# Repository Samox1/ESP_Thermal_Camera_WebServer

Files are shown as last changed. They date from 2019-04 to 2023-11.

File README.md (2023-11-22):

# ESP_Thermal_Camera_WebServer

Welcome to see the micro project based on ESP32. <br>
Thermal Camera based on: <br>
1) ESP32 (Wrover)
2) MLX 90640 Thermal Camera 32x24 pixels
3) 0.95' OLED (SD1331)
4) ESPAsyncWebServer
5) SPIFFS - file system 
<br>

Important features - TO DO LIST:
- [x] Grabbing thermal image from MLX90640
- [x] Test image on OLED
- [x] Show thermal image on OLED
- [x] Build WebServer with ESPAsyncWebServer
- [x] Automatic update of variables (e.g. MaxTemp) on Website
- [x] Save thermal image as picture (BMP) in SPIFFS
- [x] Show Thermal Image (BMP) on Website
- [x] Automatic update of BMP (suitable SetInterval in <script>)
- [x] Case - 3D Model and print it on FDM 3D Printer
- [ ] Tweak updating Thermal Image (now SetInterval set to 1 sec - buggy image if set <1sec or there is more Clients)
- [ ] Reducing overall latency (Issue #2)
- [ ] Maybe Stream thermal image to Website (because why not) - faster updating
- [ ] Add Switch on Website to On/Off OLED display

Note: 10/10/2019<br>
I have MLX90640 files that are 6 months old. The latest files from Melexis contain a bug in the MLX90640_API.cpp file.

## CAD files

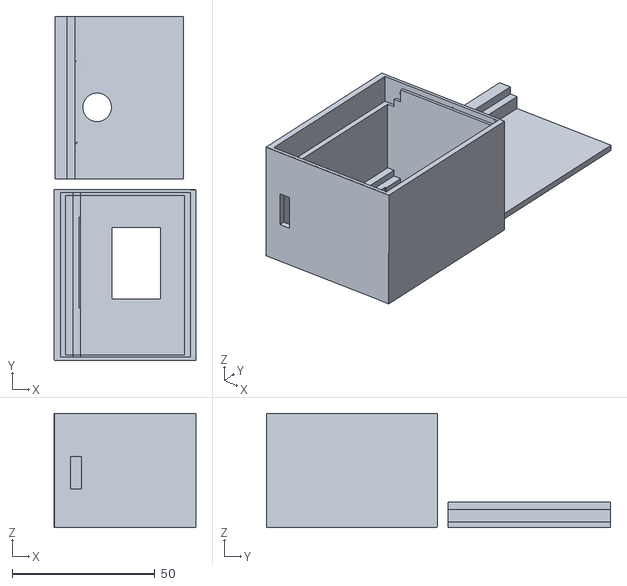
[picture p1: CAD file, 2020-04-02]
3D Model/Thermal_Camera_ESP32_MLX90640_ver_1-2_STL.stl
49.7 x 120.5 x 40.1

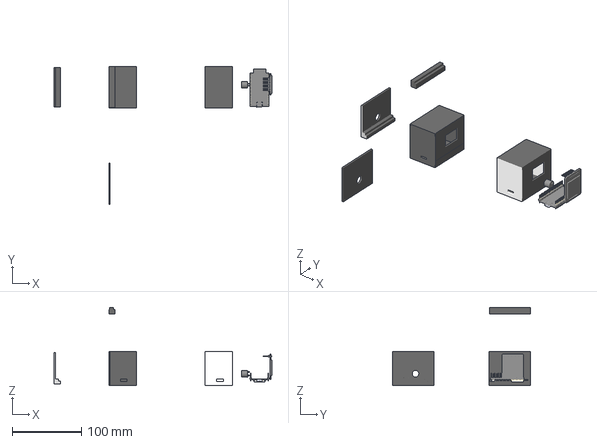
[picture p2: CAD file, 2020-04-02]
3D Model/Thermal_Camera_ESP32_MLX90640.3mf
315.5 x 199.3 x 113.2 mm

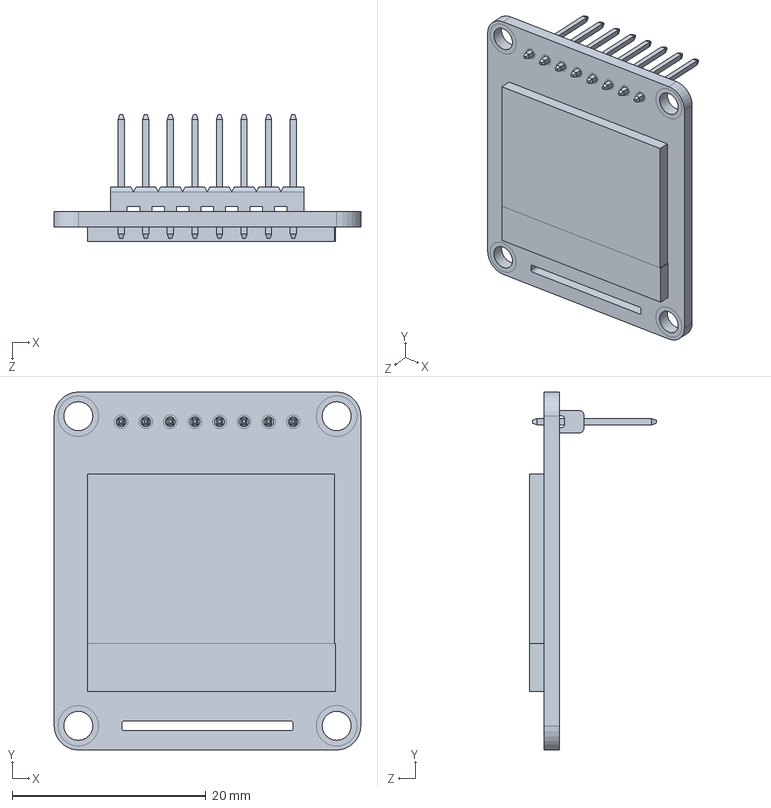
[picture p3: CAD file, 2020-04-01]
3D Model/OLED_RGB_0.95_96x64_Waveshare.SLDPRT
31.7 x 37.0 x 13.1 mm

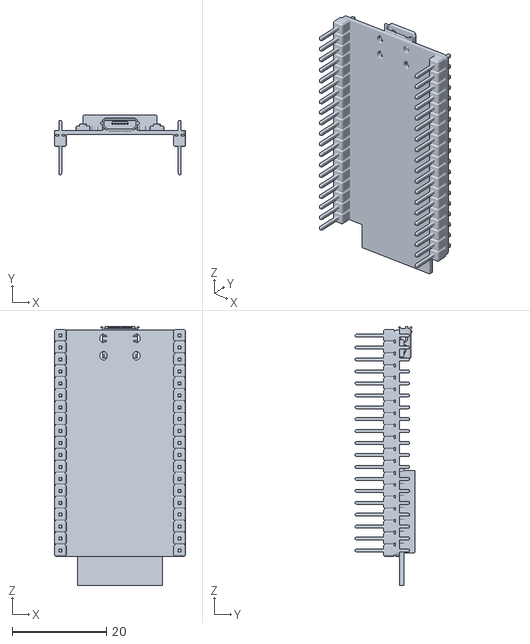
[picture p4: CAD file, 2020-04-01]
3D Model/ESP32-DEVKITC.obj
27.9 x 12.7 x 55.1

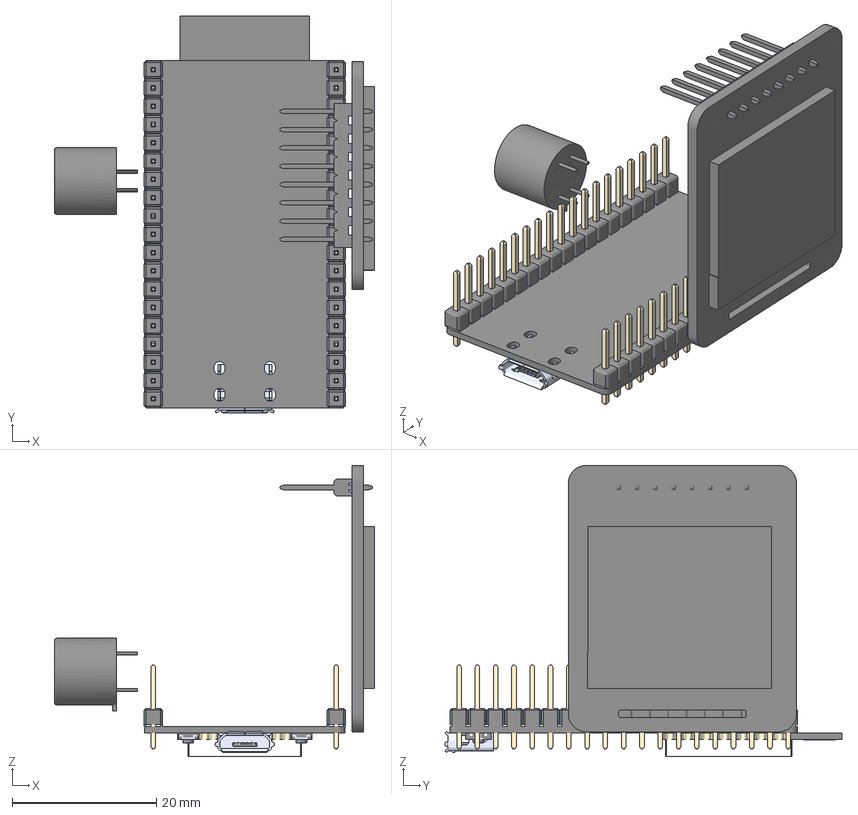
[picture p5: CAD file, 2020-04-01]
3D Model/Therm_Cam_ESP32_MLX90640_Inside.3mf
44.4 x 55.1 x 40.4 mm

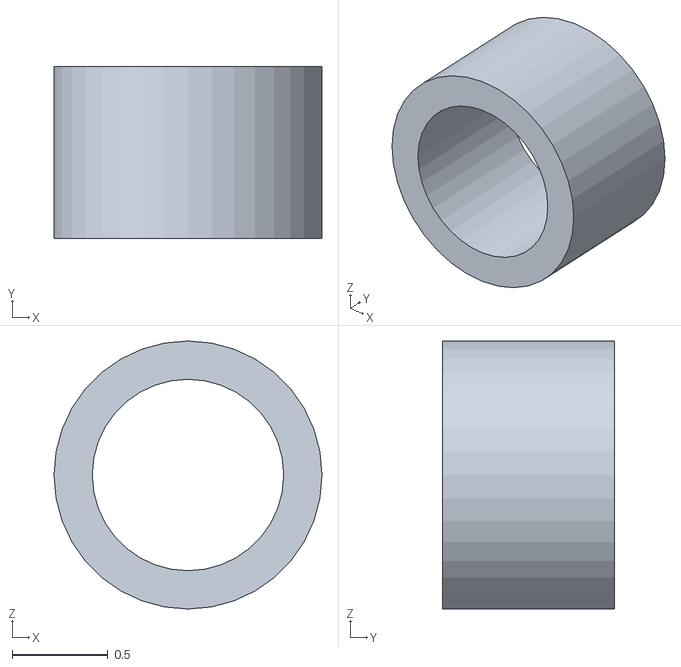
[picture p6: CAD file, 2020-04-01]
3D Model/ESP32-DEVKITC-32D.stl
1.40 x 0.9 x 1.40

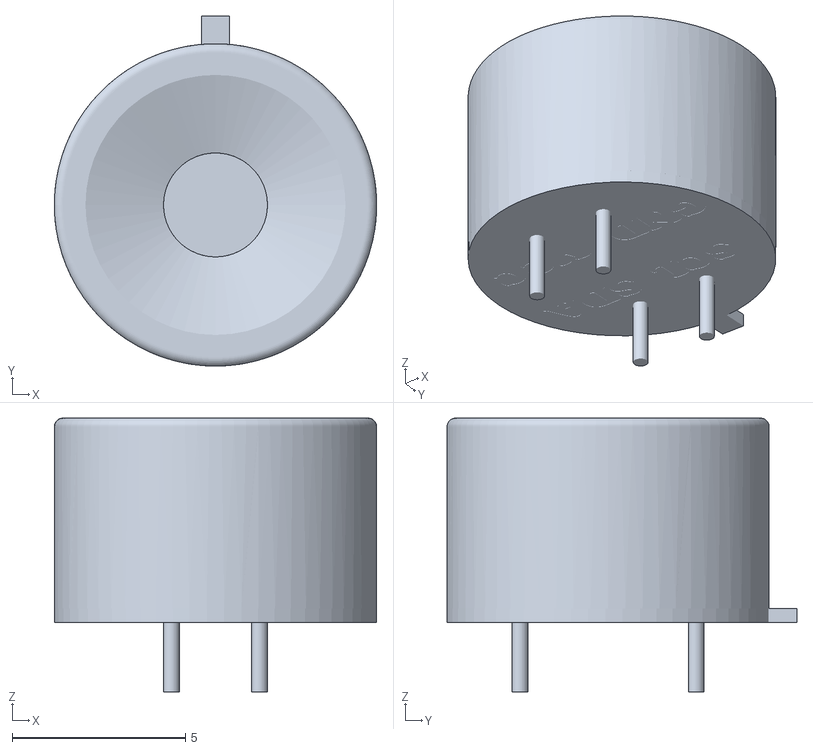
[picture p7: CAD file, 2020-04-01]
3D Model/MLX90640.STL
9.30 x 10.1 x 7.90

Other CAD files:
3D Model/Thermal_Camera_ESP32_MLX90640_ver_1-2.3mf
3D Model/OLED_RGB_0.95_96x64_Waveshare.obj

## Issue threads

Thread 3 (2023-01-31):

Help !

JatinJani, 2023-01-31:
Hello I am new to all this. I have an ESP8266 NodeMCU and MLX90640. It is connected as below :
3.3v
GND
D5 (SDA)
D4(SDL)

Can you please help and tell me how to proceed and get the image to display on a WebServer ?

Much appreciated.

Thanks.

Samox1, 2023-11-22:
Sorry for not responding... Hope you found a solution!

oficjalniebktv, 2024-02-10:
Udało wam się odszukać poprawny kod który dobrze działa z ESP8266 NodeMCU i MLX90640

Samox1, 2024-02-15:
Jeśli to jest pytanie - to na ten moment mam w planach dostosowanie kodu do nowych bibliotek i sprawdzenie działania na Arduino IDE 2.X (na ten moment 2.3.1), ale z powodu pracy i innych projektów, ten projekt jest rozłożony w czasie

oficjalniebktv, 2024-02-17:
Okey , dziękuje za odpowiedź 
W dniu 2024-02-15 10:39:49 użytkownik Szymon Baczyński ***@***.***> napisał:
 
Jeśli to jest pytanie - to na ten moment mam w planach dostosowanie kodu do nowych bibliotek i sprawdzenie działania na Arduino IDE 2.X (na ten moment 2.3.1), ale z powodu pracy i innych projektów, ten projekt jest rozłożony w czasie
—
Reply to this email directly, view it on GitHub, or unsubscribe.
You are receiving this because you commented.Message ID: ***@***.***>

oficjalniebktv, 2024-02-17:
okey dzięki za odpowiedź

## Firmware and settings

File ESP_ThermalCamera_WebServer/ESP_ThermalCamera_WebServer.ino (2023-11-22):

//--------------------------------------------------------------------------------------------------------//
// Thermal Image Camera - Project using ESP8266 or ESP32 and MLX90640 sensor (32x24 px)                   //
// Design with 0.95' OLED (SD1331) and WebServer to see images (with interpolation) on any other device   //
// Project based on MLX data sheet and examples                                                           //
// Author: Szymon Baczyński                                                                               //
// Date: April 2019                                                                                       //
// Version: Ver 1.1                                                                                       //
// GitHub: https://github.com/Samox1/ESP_Thermal_Camera_WebServer                                         //
//--------------------------------------------------------------------------------------------------------//

#include <SPI.h>
#include <Wire.h>
#include <WiFi.h>
#include <WiFiClient.h>
#include "ESPAsyncWebSrv.h"
#include "SPIFFS.h"
#include <Adafruit_GFX.h>
#include <Adafruit_SSD1331.h>
#include "MLX90640_I2C_Driver.h"
#include "MLX90640_API.h"


const byte MLX90640_address = 0x33; //Default 7-bit unshifted address of the MLX90640

#define TA_SHIFT 8 //Default shift for MLX90640 in open air

float mlx90640To[768];
paramsMLX90640 mlx90640;

// You can use any (4 or) 5 pins
#define sclk 18
#define mosi 23
#define cs   17
#define rst  5
#define dc   16


// Color definitions
#define BLACK           0x0000
#define BLUE            0x001F
#define RED             0xF800
#define GREEN           0x07E0
#define CYAN            0x07FF
#define MAGENTA         0xF81F
#define YELLOW          0xFFE0
#define WHITE           0xFFFF

#define PART_BOUNDARY "123456789000000000000987654321"

//the colors we will be using
const uint16_t camColors[] = {0x480F,
                              0x400F, 0x400F, 0x400F, 0x4010, 0x3810, 0x3810, 0x3810, 0x3810, 0x3010, 0x3010,
                              0x3010, 0x2810, 0x2810, 0x2810, 0x2810, 0x2010, 0x2010, 0x2010, 0x1810, 0x1810,
                              0x1811, 0x1811, 0x1011, 0x1011, 0x1011, 0x0811, 0x0811, 0x0811, 0x0011, 0x0011,
                              0x0011, 0x0011, 0x0011, 0x0031, 0x0031, 0x0051, 0x0072, 0x0072, 0x0092, 0x00B2,
                              0x00B2, 0x00D2, 0x00F2, 0x00F2, 0x0112, 0x0132, 0x0152, 0x0152, 0x0172, 0x0192,
                              0x0192, 0x01B2, 0x01D2, 0x01F3, 0x01F3, 0x0213, 0x0233, 0x0253, 0x0253, 0x0273,
                              0x0293, 0x02B3, 0x02D3, 0x02D3, 0x02F3, 0x0313, 0x0333, 0x0333, 0x0353, 0x0373,
                              0x0394, 0x03B4, 0x03D4, 0x03D4, 0x03F4, 0x0414, 0x0434, 0x0454, 0x0474, 0x0474,
                              0x0494, 0x04B4, 0x04D4, 0x04F4, 0x0514, 0x0534, 0x0534, 0x0554, 0x0554, 0x0574,
                              0x0574, 0x0573, 0x0573, 0x0573, 0x0572, 0x0572, 0x0572, 0x0571, 0x0591, 0x0591,
                              0x0590, 0x0590, 0x058F, 0x058F, 0x058F, 0x058E, 0x05AE, 0x05AE, 0x05AD, 0x05AD,
                              0x05AD, 0x05AC, 0x05AC, 0x05AB, 0x05CB, 0x05CB, 0x05CA, 0x05CA, 0x05CA, 0x05C9,
                              0x05C9, 0x05C8, 0x05E8, 0x05E8, 0x05E7, 0x05E7, 0x05E6, 0x05E6, 0x05E6, 0x05E5,
                              0x05E5, 0x0604, 0x0604, 0x0604, 0x0603, 0x0603, 0x0602, 0x0602, 0x0601, 0x0621,
                              0x0621, 0x0620, 0x0620, 0x0620, 0x0620, 0x0E20, 0x0E20, 0x0E40, 0x1640, 0x1640,
                              0x1E40, 0x1E40, 0x2640, 0x2640, 0x2E40, 0x2E60, 0x3660, 0x3660, 0x3E60, 0x3E60,
                              0x3E60, 0x4660, 0x4660, 0x4E60, 0x4E80, 0x5680, 0x5680, 0x5E80, 0x5E80, 0x6680,
                              0x6680, 0x6E80, 0x6EA0, 0x76A0, 0x76A0, 0x7EA0, 0x7EA0, 0x86A0, 0x86A0, 0x8EA0,
                              0x8EC0, 0x96C0, 0x96C0, 0x9EC0, 0x9EC0, 0xA6C0, 0xAEC0, 0xAEC0, 0xB6E0, 0xB6E0,
                              0xBEE0, 0xBEE0, 0xC6E0, 0xC6E0, 0xCEE0, 0xCEE0, 0xD6E0, 0xD700, 0xDF00, 0xDEE0,
                              0xDEC0, 0xDEA0, 0xDE80, 0xDE80, 0xE660, 0xE640, 0xE620, 0xE600, 0xE5E0, 0xE5C0,
                              0xE5A0, 0xE580, 0xE560, 0xE540, 0xE520, 0xE500, 0xE4E0, 0xE4C0, 0xE4A0, 0xE480,
                              0xE460, 0xEC40, 0xEC20, 0xEC00, 0xEBE0, 0xEBC0, 0xEBA0, 0xEB80, 0xEB60, 0xEB40,
                              0xEB20, 0xEB00, 0xEAE0, 0xEAC0, 0xEAA0, 0xEA80, 0xEA60, 0xEA40, 0xF220, 0xF200,
                              0xF1E0, 0xF1C0, 0xF1A0, 0xF180, 0xF160, 0xF140, 0xF100, 0xF0E0, 0xF0C0, 0xF0A0,
                              0xF080, 0xF060, 0xF040, 0xF020, 0xF800,
                             };

//WebServer server(80);
// Create AsyncWebServer object on port 80
AsyncWebServer server(80);

//Enter your SSID and PASSWORD
const char* ssid = "ESP";
const char* password = "camera";

float p = 3.1415926;
Adafruit_SSD1331 display = Adafruit_SSD1331(cs, dc, mosi, sclk, rst);

float MaxTemp = 0;
float MinTemp = 0;
float CenterTemp = 0;


String getCenterTemp(){
  extern float CenterTemp;
  return String(CenterTemp);
}
String getMaxTemp(){
  extern float MaxTemp;
  return String(MaxTemp);
}
String getMinTemp(){
  extern float MinTemp;
  return String(MinTemp);
}

const char index_html[] PROGMEM = R"rawliteral(
<!DOCTYPE HTML><html>
<head>
  <meta name="viewport" content="width=device-width, initial-scale=1">
  <link rel="stylesheet" href="https://use.fontawesome.com/releases/v5.7.2/css/all.css" integrity="sha384-fnmOCqbTlWIlj8LyTjo7mOUStjsKC4pOpQbqyi7RrhN7udi9RwhKkMHpvLbHG9Sr" crossorigin="anonymous">
  <style>
    html {
     font-family: Arial;
     display: inline-block;
     margin: 0px auto;
     text-align: center;
    }
    h2 { font-size: 3.0rem; }
    p { font-size: 3.0rem; }
    .units { font-size: 1.2rem; }
    .dht-labels{
      font-size: 1.5rem;
      vertical-align:middle;
      padding-bottom: 15px;
    }
    img { 
      display: inline-block;
      vertical-align: middle;
      max-height: 100%;
      max-width: 100%;
    }
  </style>
</head>
<body>
  <h2>ESP32 Thermal Camera</h2>
  <p>
    <i class="fas fa-thermometer-half" style="color:#059e8a;"></i> 
    <span class="dht-labels">Temperature: </span> 
    <span id="temperature">%TEMPERATURE%</span>
    <sup class="units">&deg;C</sup><br>
    
    <span class="dht-labels">Temp Max: </span> 
    <span id="tempmax">%TEMPMAX%</span>
    <sup class="units">&deg;C</sup><br>
    
    <span class="dht-labels">Temp Min: </span> 
    <span id="tempmin">%TEMPMIN%</span>
    <sup class="units">&deg;C</sup>

    <img src="thermal" id="thermalimage" style="width: 100%">
  </p>
</body>
<script>

setInterval(function ( ) {
  var xhttp = new XMLHttpRequest();
  xhttp.onreadystatechange = function() {
    if (this.readyState == 4 && this.status == 200) {
      document.getElementById("temperature").innerHTML = this.responseText;
    }
  };
  xhttp.open("GET", "/temperature", true);
  xhttp.send();
}, 1000 ) ;

setInterval(function ( ) {
  var xhttp = new XMLHttpRequest();
  xhttp.onreadystatechange = function() {
    if (this.readyState == 4 && this.status == 200) {
      document.getElementById("tempmax").innerHTML = this.responseText;
    }
  };
  xhttp.open("GET", "/tempmax", true);
  xhttp.send();
}, 1000 ) ;

setInterval(function ( ) {
  var xhttp = new XMLHttpRequest();
  xhttp.onreadystatechange = function() {
    if (this.readyState == 4 && this.status == 200) {
      document.getElementById("tempmin").innerHTML = this.responseText;
    }
  };
  xhttp.open("GET", "/tempmin", true);
  xhttp.send();
}, 1000 ) ;

setInterval(function ( ) {
  var xhttp = new XMLHttpRequest();
  xhttp.onreadystatechange = function() {
    //if (this.readyState == 4 && this.status == 200) {
      var image = document.getElementById("thermalimage");
      //image.src = this.response;
      image.src = "thermal";
      //document.getElementById("thermal") = this.response;
    //}
  };
  xhttp.open("GET", "/thermal", true);
  xhttp.send();
}, 1000 ) ;

</script>
</html>)rawliteral";


// Replaces placeholder with values
String processor(const String& var){
  //Serial.println(var);
  if(var == "TEMPERATURE"){
    return getCenterTemp();
  }
  if(var == "TEMPMAX"){
    return getMaxTemp();
  }
  if(var == "TEMPMIN"){
    return getMinTemp();
  }
  
  return String();
}


//Returns true if the MLX90640 is detected on the I2C bus
boolean isConnected()
{
  Wire.beginTransmission((uint8_t)MLX90640_address);
  if (Wire.endTransmission() != 0)
    return (false); //Sensor did not ACK
  return (true);
}


//void getThermalImage(){ }


void ThermalImageToWeb(float mlx90640To[], float MinTemp, float MaxTemp)
{
  // --- SAVE BMP FILE --- //
  uint8_t colorIndex = 0;
  uint16_t color = 0;
  unsigned int headers[13];
  int extrabytes;
  int paddedsize;
  int x = 0; 
  int y = 0; 
  int n = 0;
  int red = 0;
  int green = 0;
  int blue = 0;
  
  int WIDTH = 32;
  int HEIGHT = 24;

  extrabytes = 4 - ((WIDTH * 3) % 4);                 // How many bytes of padding to add to each
                                                    // horizontal line - the size of which must
                                                    // be a multiple of 4 bytes.
  if (extrabytes == 4)
    extrabytes = 0;

  paddedsize = ((WIDTH * 3) + extrabytes) * HEIGHT;

// Headers...
// Note that the "BM" identifier in bytes 0 and 1 is NOT included in these "headers".

  headers[0]  = paddedsize + 54;      // bfSize (whole file size)
  headers[1]  = 0;                    // bfReserved (both)
  headers[2]  = 54;                   // bfOffbits
  headers[3]  = 40;                   // biSize
  headers[4]  = WIDTH;                // biWidth
  headers[5]  = HEIGHT;               // biHeight

// Would have biPlanes and biBitCount in position 6, but they're shorts.
// It's easier to write them out separately (see below) than pretend
// they're a single int, especially with endian issues...

  headers[7]  = 0;                    // biCompression
  headers[8]  = paddedsize;           // biSizeImage
  headers[9]  = 0;                    // biXPelsPerMeter
  headers[10] = 0;                    // biYPelsPerMeter
  headers[11] = 0;                    // biClrUsed
  headers[12] = 0;                    // biClrImportant

// outfile = fopen(filename, "wb");

  File file = SPIFFS.open("/thermal.bmp", "wb");
  if (!file) {
    Serial.println("There was an error opening the file for writing");
    //return;
  }else{

// Headers begin...
// When printing ints and shorts, we write out 1 character at a time to avoid endian issues.

  file.print("BM");

  for (n = 0; n <= 5; n++)
  { 
    file.printf("%c", headers[n] & 0x000000FF);
    file.printf("%c", (headers[n] & 0x0000FF00) >> 8);
    file.printf("%c", (headers[n] & 0x00FF0000) >> 16);
    file.printf("%c", (headers[n] & (unsigned int) 0xFF000000) >> 24);
  }

// These next 4 characters are for the biPlanes and biBitCount fields.

  file.printf("%c", 1);
  file.printf("%c", 0);
  file.printf("%c", 24);
  file.printf("%c", 0);

  for (n = 7; n <= 12; n++)
  {
    file.printf("%c", headers[n] & 0x000000FF);
    file.printf("%c", (headers[n] & 0x0000FF00) >> 8);
    file.printf("%c", (headers[n] & 0x00FF0000) >> 16);
    file.printf("%c", (headers[n] & (unsigned int) 0xFF000000) >> 24);
  }

// Headers done, now write the data...

  for (y = HEIGHT - 1; y >= 0; y--)     // BMP image format is written from bottom to top...
  {
    for (x = 0; x <= WIDTH - 1; x++)
    {
      // --- Read ColorIndex corresponding to Pixel Temperature --- //
      colorIndex = map(mlx90640To[x+(32*y)], MinTemp-5.0, MaxTemp+5.0, 0, 255);
      colorIndex = constrain(colorIndex, 0, 255);
      color = camColors[colorIndex];
      
      // --- Converts 4 Digits HEX to RGB565 --- //
      // uint8_t r = ((color >> 11) & 0x1F);
      // uint8_t g = ((color >> 5) & 0x3F);
      // uint8_t b = (color & 0x1F);

      // --- Converts 4 Digits HEX to RGB565 -> RGB888 --- //
      red = ((((color >> 11) & 0x1F) * 527) + 23) >> 6;
      green = ((((color >> 5) & 0x3F) * 259) + 33) >> 6;
      blue = (((color & 0x1F) * 527) + 23) >> 6;

      // --- RGB range from 0 to 255 --- //
      if (red > 255) red = 255; if (red < 0) red = 0;
      if (green > 255) green = 255; if (green < 0) green = 0;
      if (blue > 255) blue = 255; if (blue < 0) blue = 0;

      // Also, it's written in (b,g,r) format...

      file.printf("%c", blue);
      file.printf("%c", green);
      file.printf("%c", red);
    }
    if (extrabytes)      // See above - BMP lines must be of lengths divisible by 4.
    {
      for (n = 1; n <= extrabytes; n++)
      {
         file.printf("%c", 0);
      }
    }
  }

  file.close();
  Serial.println("File Closed");
  }         // --- END SAVING BMP FILE --- //
}


void lcdThermalImage(float mlx90640To[], float MinTemp, float MaxTemp)
{
  uint8_t w,h;
  uint8_t box = 2;
  display.setAddrWindow(0, 0, 96, 64);
  
  for (h = 0; h < 24; h++) {
    for (w = 0; w < 32; w++) {
      uint8_t colorIndex = map(mlx90640To[w+(32*h)], MinTemp-5.0, MaxTemp+5.0, 0, 255);
      colorIndex = constrain(colorIndex, 0, 255);
      
      display.fillRect(box * w, box * h, box, box, camColors[colorIndex]);
      //display.writePixel(w, h, camColors[colorIndex]);
    }  
  }
  display.endWrite();
}


void lcdTestThermalImage(void)
{
  uint8_t w,h;
  display.setAddrWindow(0, 0, 96, 64);

  for (h = 0; h < 48; h++) {
    for (w = 0; w < 64; w++) {
      if (h*w <= 255) {
        display.writePixel(w, h, camColors[h*w]);
      } else{
        display.writePixel(w, h, RED);
      }
    }
  }
  display.endWrite();
}

void MLX_to_Serial(float mlx90640To[])
{
  for (int x = 0 ; x < 768 ; x++)
  {
    //Serial.print("Pixel ");
    Serial.print(x);
    Serial.print(": ");
    Serial.print(mlx90640To[x], 2);
    //Serial.print("C");
    Serial.println();
  }
}


// SETUP
//==========================================================================

void setup()
{
  Wire.begin();
  Wire.setClock(400000); //Increase I2C clock speed to 400kHz
  Serial.begin(115200);while (!Serial); //Wait for user to open terminal

  if(!SPIFFS.begin(true)){
      Serial.println("An Error has occurred while mounting SPIFFS");
      return;
}
  //ESP32 As access point
  WiFi.mode(WIFI_AP); //Access Point mode
  WiFi.softAP(ssid, password);
  
  Serial.print("SDA pin: "); Serial.println(SDA);
  Serial.print("SCL pin: ");Serial.println(SCL);
  
  Serial.println("MLX90640 IR Array Example");

  if (isConnected() == false)
  {
    Serial.println("MLX90640 not detected at default I2C address. Please check wiring. Freezing.");
    while (1);
  }
  Serial.println("MLX90640 online!");

  //Get device parameters - We only have to do this once
  int status=0;
  uint16_t eeMLX90640[832];
  status = MLX90640_DumpEE(MLX90640_address, eeMLX90640);
  if (status != 0)
    Serial.println("Failed to load system parameters");

  status = MLX90640_ExtractParameters(eeMLX90640, &mlx90640);
  if (status != 0)
    Serial.println("Parameter extraction failed");
  
  int SetRefreshRate = 0;
  SetRefreshRate = MLX90640_SetRefreshRate(0x33,0x03);
  //int SetInterleavedMode = MLX90640_SetInterleavedMode(MLX90640_address);
  int SetChessMode = MLX90640_SetChessMode(MLX90640_address);
  

// --- Part Display OLED --- //

  display.begin();

  Serial.println("init");
  uint16_t time = millis();
  display.fillScreen(BLACK);
  time = millis() - time;
  Serial.println(time, DEC);
  delay(500);


  display.fillScreen(BLACK);
  display.setCursor(0,0);
  display.print("Welcome!\nThis is example of Thermal Image Camera based on MLX90640 sensor.\n by SamoX");
  delay(2000);
  display.fillScreen(BLACK);
  lcdTestThermalImage();
  delay(1000);
  //display.fillScreen(BLACK);
  //Once params are extracted, we can release eeMLX90640 array

// --- Part WebServer ESP --- //
  
  //IPAddress ServerIP = WiFi.softAPIP(); // Obtain the IP of the Serve
  //Serial.print("IP address: ");
  //Serial.println(ServerIP);   //IP address assigned to your ESP
  //display.setCursor(0,49);
  //display.print(ServerIP);    // IP address on Display
//----------------------------------------------------------------

  // Route for root / web page
  //server.on("/", HTTP_GET, [](AsyncWebServerRequest *request){
  //  request->send_P(200, "text/html", index_html, processor);
  //  //request->send_P(200, "text/html", index_html);
  //});
  //server.on("/temperature", HTTP_GET, [](AsyncWebServerRequest *request){
  //  request->send_P(200, "text/plain", getCenterTemp().c_str());
  //});
  //server.on("/tempmax", HTTP_GET, [](AsyncWebServerRequest *request){
  //  request->send_P(200, "text/plain", getMaxTemp().c_str());
  //});
  //server.on("/tempmin", HTTP_GET, [](AsyncWebServerRequest *request){
  //  request->send_P(200, "text/plain", getMinTemp().c_str());
  //});
  //server.on("/thermal", HTTP_GET, [](AsyncWebServerRequest *request){
  //  request->send(SPIFFS, "/thermal.bmp", "image/bmp", false);
  //});

  //server.begin();                  //Start server
  //Serial.println("HTTP server started");
}


// LOOP
//===========================================================================

void loop()
{
  // Read Thermal Image from MLX90640
  for (byte x = 0 ; x < 2 ; x++) //Read both subpages
  {
    uint16_t mlx90640Frame[834];
    int status = MLX90640_GetFrameData(MLX90640_address, mlx90640Frame);
    if (status < 0)
    {
      Serial.print("GetFrame Error: ");
      Serial.println(status);
    }

    float vdd = MLX90640_GetVdd(mlx90640Frame, &mlx90640);
    float Ta = MLX90640_GetTa(mlx90640Frame, &mlx90640);

    float tr = Ta - TA_SHIFT; //Reflected temperature based on the sensor ambient temperature
    float emissivity = 0.95;

    MLX90640_CalculateTo(mlx90640Frame, &mlx90640, emissivity, tr, mlx90640To);
  }

  // --- START of Calculate Chess Mode --- //
    // Calculate difference between Subpages (chess-mode)
/*    int pa = 0;
    int niepa = 0;
    float sumpa = 0;
    float sumniepa = 0;

    int w = 32;
    int h = 24;

    for(int i=0; i<h; i++) {
      for(int j=0; j<w; j++) {
        if((i+j)%2 == 0){
          //Serial.println(j+(w*i));
          sumpa = mlx90640To[j+(w*i)];
          pa++;
        }else{
          //Serial.print("*"); Serial.println(j+(w*i));
          sumniepa = mlx90640To[j+(w*i)];
          niepa++;
        }
      }
    }

    sumpa = sumpa / (float)pa;
    sumniepa = sumniepa / (float)niepa;
    float diff = sumpa - sumniepa;          // Difference between even and odd 
    
    if(diff < 0.0){
      for(int i=0; i<h; i++) {
        for(int j=0; j<w; j++) {
          if((i+j)%2 == 0){
            mlx90640To[j+(w*i)] += abs(diff); 
          }else{
            //mlx90640To[j+(w*i)] += abs(diff);
          }
        }
      }
    }else{
       for(int i=0; i<h; i++) {
        for(int j=0; j<w; j++) {
          if((i+j)%2 == 0){
            //mlx90640To[j+(w*i)] += abs(diff); 
          }else{
            mlx90640To[j+(w*i)] += abs(diff);
          }
        }
      }
    }       */
// --- END of Calculate Chess Mode --- //

    CenterTemp = (mlx90640To[367]+mlx90640To[368]+mlx90640To[399]+mlx90640To[400]) / 4.0;  // Temp in Center - based on 4 pixels

    MaxTemp = mlx90640To[0];            // Get first data to find Max and Min Temperature
    MinTemp = mlx90640To[0];
    
    for (int x = 0 ; x < 768 ; x++)     // Find Maximum and Minimum Temperature
    {
      if (mlx90640To[x] > MaxTemp){
        MaxTemp = mlx90640To[x];
      }
      if (mlx90640To[x] < MinTemp){
        MinTemp = mlx90640To[x];
      }
    }


    //ThermalImageToWeb(mlx90640To, MinTemp, MaxTemp);
    //display.fillRect(0, 0, 96, 48, BLACK);    // Black important sector - image and text on right side
    
    lcdThermalImage(mlx90640To, MinTemp, MaxTemp);    // Function to draw Thermal Image on OLED 

    display.fillRect(66, 0, 30, 48, BLACK);     // Black only text with Max, Center and Min temperature
    
    display.setCursor(66,0);                    // Text with Max, Center and Min Temperature on right side
    display.setTextColor(RED);
    display.print(MaxTemp,2);

    display.setCursor(66,18);
    display.setTextColor(WHITE);
    display.print(CenterTemp,2);
    
    display.setCursor(66,36);
    display.setTextColor(BLUE);
    display.print(MinTemp,2);
 
    //MLX_to_Serial(mlx90640To);
    //display.fillScreen(BLACK);
    
  delay(100);
}

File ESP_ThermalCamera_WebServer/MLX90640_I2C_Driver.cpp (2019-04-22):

/**
   @copyright (C) 2017 Melexis N.V.

   Licensed under the Apache License, Version 2.0 (the "License");
   you may not use this file except in compliance with the License.
   You may obtain a copy of the License at

       http://www.apache.org/licenses/LICENSE-2.0

   Unless required by applicable law or agreed to in writing, software
   distributed under the License is distributed on an "AS IS" BASIS,
   WITHOUT WARRANTIES OR CONDITIONS OF ANY KIND, either express or implied.
   See the License for the specific language governing permissions and
   limitations under the License.

*/


#include <Wire.h>

#include "MLX90640_I2C_Driver.h"

void MLX90640_I2CInit()
{

}

//Read a number of words from startAddress. Store into Data array.
//Returns 0 if successful, -1 if error
int MLX90640_I2CRead(uint8_t _deviceAddress, unsigned int startAddress, unsigned int nWordsRead, uint16_t *data)
{

  //Caller passes number of 'unsigned ints to read', increase this to 'bytes to read'
  uint16_t bytesRemaining = nWordsRead * 2;

  //It doesn't look like sequential read works. Do we need to re-issue the address command each time?

  uint16_t dataSpot = 0; //Start at beginning of array

  //Setup a series of chunked I2C_BUFFER_LENGTH byte reads
  while (bytesRemaining > 0)
  {
    Wire.beginTransmission(_deviceAddress);
    Wire.write(startAddress >> 8); //MSB
    Wire.write(startAddress & 0xFF); //LSB
    if (Wire.endTransmission(false) != 0) //Do not release bus
    {
      //Serial.println("No ack read");
      return (0); //Sensor did not ACK
    }

    uint16_t numberOfBytesToRead = bytesRemaining;
    if (numberOfBytesToRead > I2C_BUFFER_LENGTH) numberOfBytesToRead = I2C_BUFFER_LENGTH;

    Wire.requestFrom((uint8_t)_deviceAddress, numberOfBytesToRead);
    if (Wire.available())
    {
      for (uint16_t x = 0 ; x < numberOfBytesToRead / 2; x++)
      {
        //Store data into array
        data[dataSpot] = Wire.read() << 8; //MSB
        data[dataSpot] |= Wire.read(); //LSB

        dataSpot++;
      }
    }

    bytesRemaining -= numberOfBytesToRead;

    startAddress += numberOfBytesToRead / 2;
  }

  return (0); //Success
}

//Set I2C Freq, in kHz
//MLX90640_I2CFreqSet(1000) sets frequency to 1MHz
void MLX90640_I2CFreqSet(int freq)
{
  //i2c.frequency(1000 * freq);
  Wire.setClock((long)1000 * freq);
}

//Write two bytes to a two byte address
int MLX90640_I2CWrite(uint8_t _deviceAddress, unsigned int writeAddress, uint16_t data)
{
  Wire.beginTransmission((uint8_t)_deviceAddress);
  Wire.write(writeAddress >> 8); //MSB
  Wire.write(writeAddress & 0xFF); //LSB
  Wire.write(data >> 8); //MSB
  Wire.write(data & 0xFF); //LSB
  if (Wire.endTransmission() != 0)
  {
    //Sensor did not ACK
    //Serial.println("Error: Sensor did not ack");
    return (-1);
  }

  uint16_t dataCheck;
  MLX90640_I2CRead(_deviceAddress, writeAddress, 1, &dataCheck);
  if (dataCheck != data)
  {
    //Serial.println("The write request didn't stick");
    return -2;
  }

  return (0); //Success
}

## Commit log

2019-04-23 Working OLED Display and MLX sensor
    Clean Code
2020-04-01 1 try to make 3D model of Case
    [ESP32-DEVKITC-32D.stl, ESP32-DEVKITC.obj, MLX90640.STL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]
2020-04-02 Learn how to 3D model Case for Thermal Camera
    [Thermal_Camera_ESP32_MLX90640.3mf, Thermal_Camera_ESP32_MLX90640_ver_1-0.stl, Thermal_Camera_ESP32_MLX90640_ver_1-1_Enclousure_Body.stl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]
2020-04-03 3D Model = Done || Next time need to do better Enclousure (it is not ideal)
    [Thermal_Camera_ESP32_MLX90640_ver_1-0.stl, Thermal_Camera_ESP32_MLX90640_ver_1-1_Enclousure_Body.stl, Thermal_Camera_ESP32_MLX90640_ver_1-1_Main_Body.stl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]
2023-11-22 Preparing tests on Arduino 2.2.1 + Adapt PR #1
